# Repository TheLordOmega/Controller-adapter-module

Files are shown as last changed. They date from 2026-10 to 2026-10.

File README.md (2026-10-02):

# Dongle Host Module for HackXpansion console

A USB-host bridge module that lets a full sized controller to be be read by the Hackxpansion console.

Key features:
* Raspberry Pi Pico as the USB host controller
* Boost-converter-fed VBUS so the Pico can power the dongle
* UART link to the console over the J1 connector
## PCB

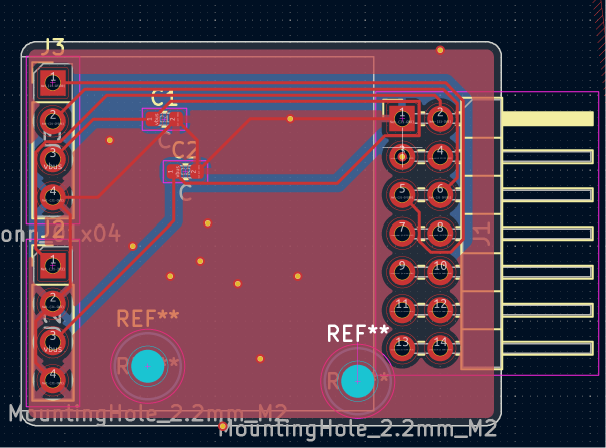
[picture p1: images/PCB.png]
PCB

## Schematic
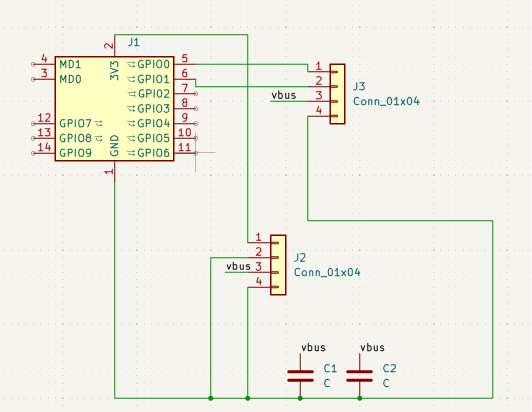
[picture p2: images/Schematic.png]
Schematic


## 3D Case
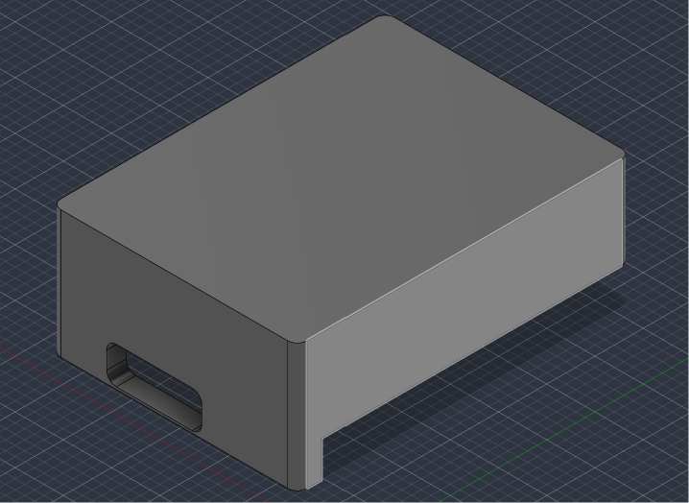
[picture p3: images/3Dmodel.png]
Case


## Bill of Materials (excluding console)
Also found in [bom.csv](./bom.csv).

| Item | Price per unit | Nr of units | Total price | Link |
| --- | --- | --- | --- | --- |
| Raspberry Pi Pico | $4.00 | 1 | $4.00 | https://www.raspberrypi.com/products/raspberry-pi-pico/ |
| MT3608 boost converter breakout | ~$1-4 (pack pricing varies) | 1 | ~$1-4 | - |
| 2x20 2.54mm female pin socket (Pico mount)  |  - | 1 | - | - |
| 2x7 2.54mm pin header (J1) | ~$0.20-0.39 | 1 | ~$0.20-0.39 | https://www.aliexpress.com/item/4000186187780.html |
| 1x04 2.54mm pin header (boost converter) | ~$0.10 | 1 | ~$0.10 | - |
| 1x02 2.54mm pin header + jumper (power cut) | ~$0.10 | 1 | ~$0.10 | - |
| MD0/MD1 ID resistors, 0603 |- | 2 | - | - |
| 10uF electrolytic + 100nF ceramic cap | - | 1 each | - | - |
| Micro-USB-to-USB-A OTG adapter cable |  - | 1 | - | - |
| PCB fab | - | 1 | - | https://jlcpcb.com/ |
| **Total** | | | ~$10 without controller | |

## Credits
* USB host HID parsing (DS4 report handling): [TinyUSB](https://github.com/hathach/tinyusb),
  `examples/host/hid_controller/src/hid_app.c`, by hathach and contributors
* Console-side UART driver pattern:   [`wardriving-driver`](https://docs.rs/crate/wardriving-driver) crate's UART bus usage
* Driver : [`xpanse_api`](https://docs.rs/xpanse-api)
* Raspberry Pi Pico hardware: [Raspberry Pi](https://www.raspberrypi.com/products/raspberry-pi-pico/)
* Thanks to Hack Club and the HackXpansion team for the console platform this module plugs into: https://github.com/hackclub/hackxpansion
* Thanks to the OpenSplitDeck project for the dongle this module is built to read as an example

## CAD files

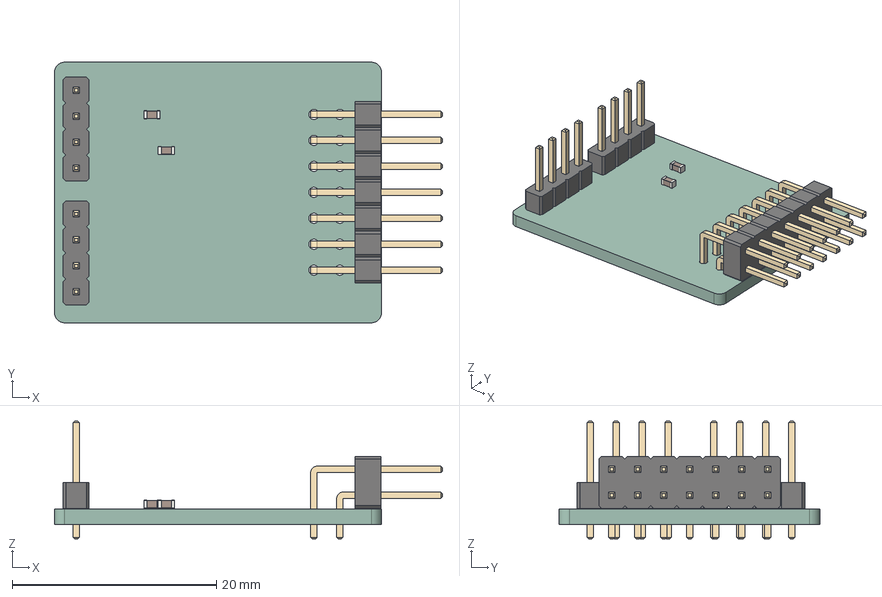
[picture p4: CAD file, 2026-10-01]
controller - pcb/controller - pcb.step
38.0 x 25.5 x 11.5 mm
PinHeader_1x04_P254mm_Vertical x 2
C_0603_1608Metric x 2
PinHeader_2x07_P254mm_Horizontal
dongle for controller-unsaved-export-7dcPdV_PCB

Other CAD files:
host bridge module.f3d

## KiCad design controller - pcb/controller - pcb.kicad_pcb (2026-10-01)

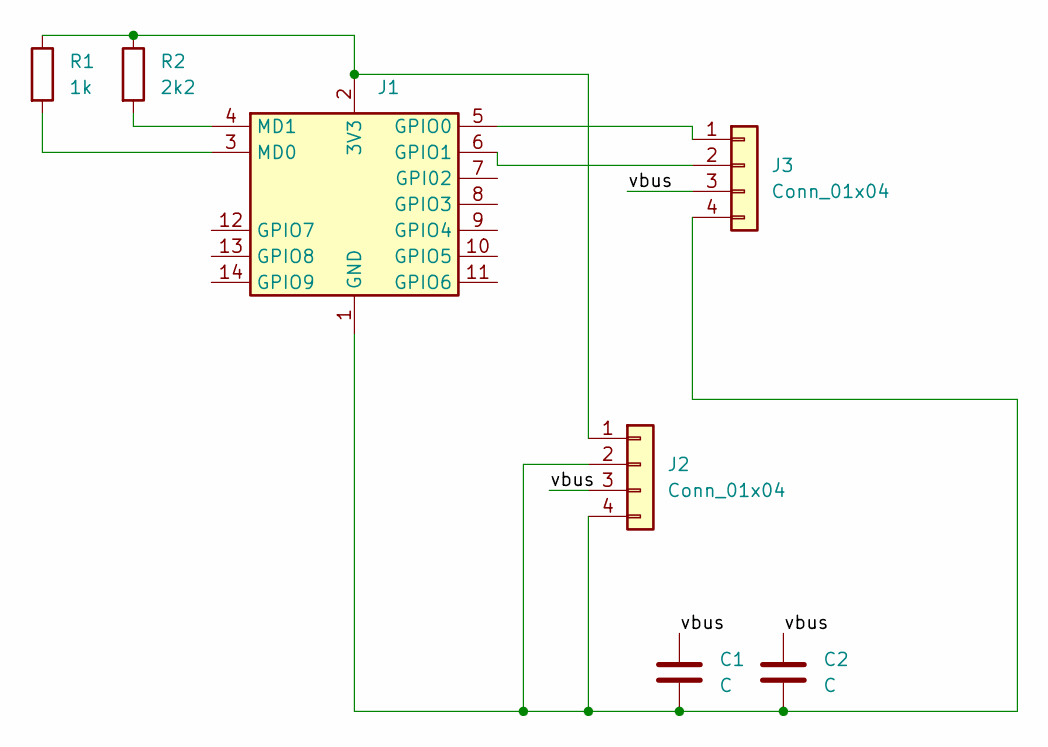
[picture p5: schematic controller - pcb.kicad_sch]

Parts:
C1, C2: C; C_0603_1608Metric
J1: Male_Module
J2, J3: Conn_01x04; PinHeader_1x04_P2.54mm_Vertical
R1: 1k; R_0603_1608Metric
R2: 2k2; R_0603_1608Metric

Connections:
/vbus: C1.1, C2.1, J2.3, J3.3
unnamed: J1.2 (3V3), J2.1, R1.1, R2.1
unnamed: C1.2, C2.2, J1.1 (GND), J2.2, J2.4, J3.4
unnamed: J1.5 (GPIO0), J3.1
unnamed: J1.6 (GPIO1), J3.2
unnamed: J1.3 (MD0), R1.2
unnamed: J1.4 (MD1), R2.2

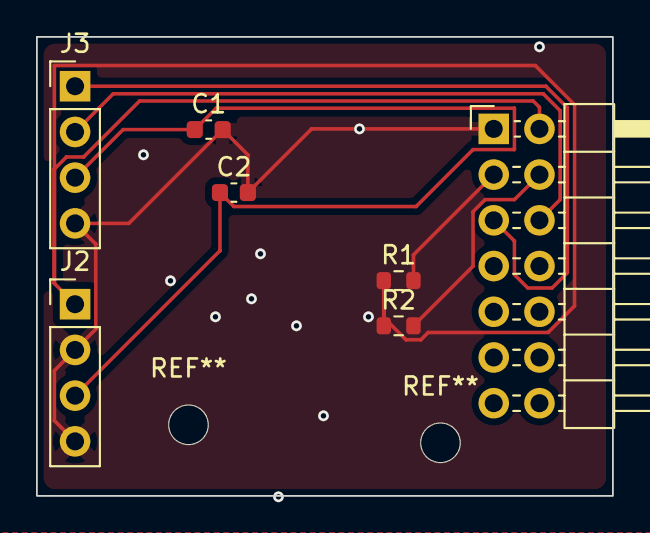
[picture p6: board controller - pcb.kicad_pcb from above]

Board: 2 copper layers, 32.0 x 25.5 mm, 7 parts (0 on the bottom side), 7 nets.

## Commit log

2026-10-01 inital commit
    [controller - pcb.kicad_pcb, controller - pcb.kicad_sch, controller - pcb.step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]
2026-10-02 Rename Pasted image 20261001225125.png to Schematic
2026-10-02 Update PCB image and add schematic section
2026-10-02 Fix formatting and update schematic image reference
2026-10-02 Rename Pasted image 20261001225337.png to PCB.png
